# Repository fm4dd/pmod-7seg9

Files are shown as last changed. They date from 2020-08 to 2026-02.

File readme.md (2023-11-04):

## 7SEG9 PMOD



### Description

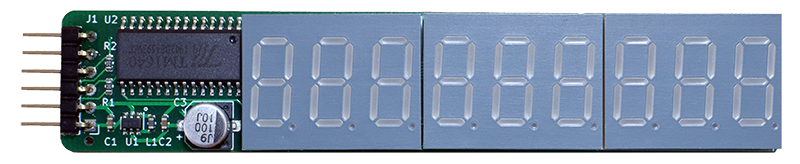
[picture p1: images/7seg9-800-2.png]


This PMOD provides a 9-digit (3x3) 7-segment LED display output to FPGA designs via a single row PMOD connector. The LED segments are driven by the TM1640 LED driver IC from Titan Microelectronics. The TM1640 can only handle "common cathode" display types. It implements the required multiplexing, LED resistance and 8-level output power control that greatly reduces the passive components needed to drive LED displays. The TM1640 driver IC interfaces with application logic through a simplified two-wire serial protocol that has similarities with I2C. A small DCDC boost converter SGM6603 raises the 3.3V PMOD voltage to the 5V operating voltage needed by the TM1640 driver IC.

http://fpga.fm4dd.com/

*Note:* The 7SEG9 PMOD draws 220-250mA current over 9 digits. During power on/off, the peak current can reach 500mA. This needs attention for boards with weak power supply.

### Schematic
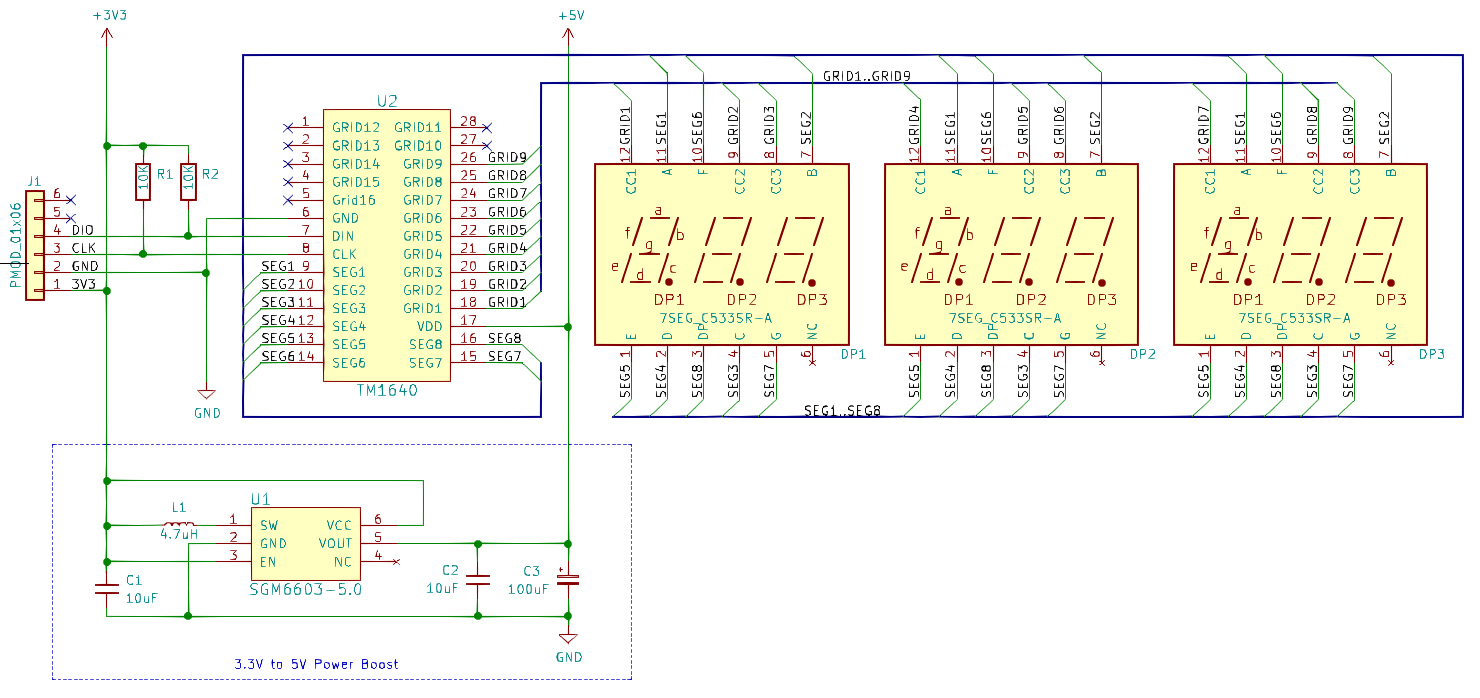
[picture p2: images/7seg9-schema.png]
7SEG9 PMOD Schematics


### PCB Gerber
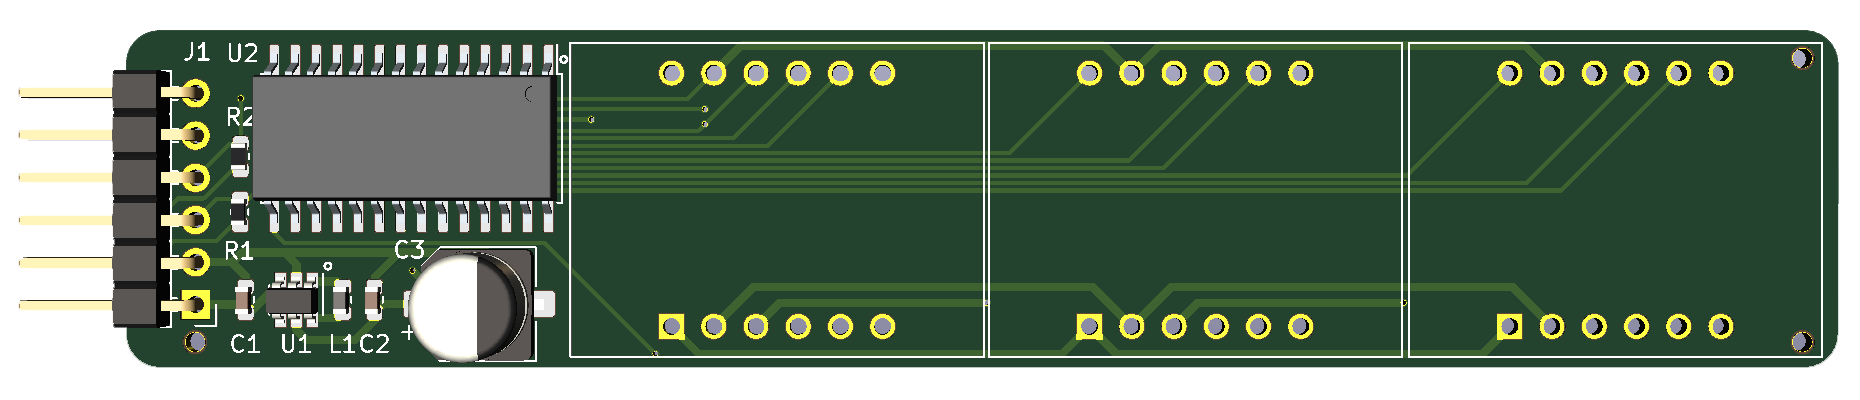
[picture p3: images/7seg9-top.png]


[7SEG4 PMOD Gerber V1.2](fabfiles/v12/20200520-7seg9-gerber-v12.zip)

### Pin Assignments

<table>
  <tr><th>PMOD Pinout</th><th>Pin</th><th>Label</th><th>Function</th></tr>
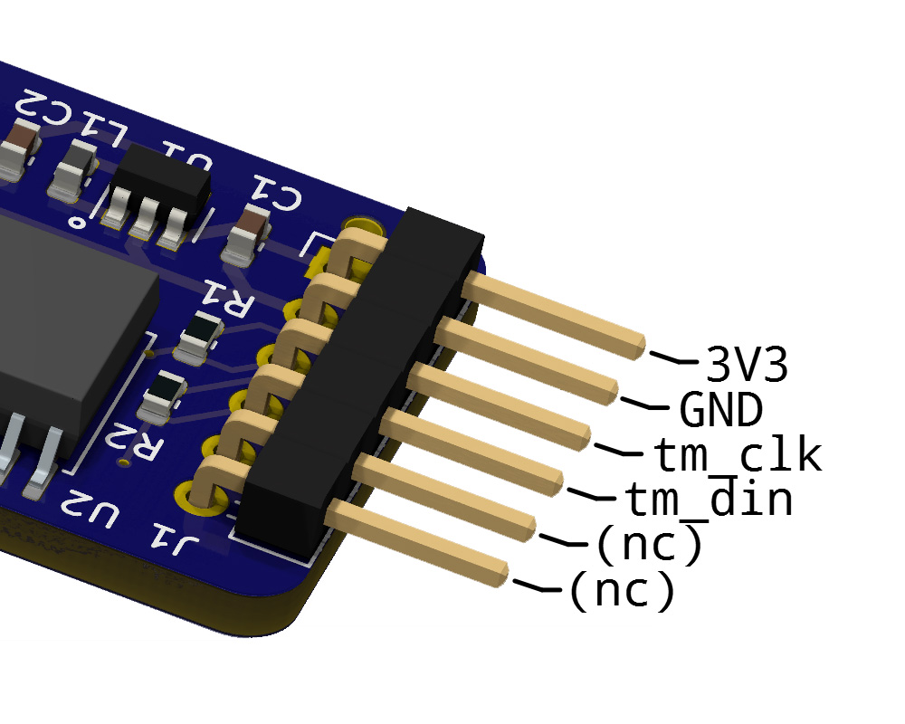
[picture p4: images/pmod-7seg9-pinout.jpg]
  <tr><td rowspan="6"></td>
    <td>1</td><td>n/c</td><td>(not connected)</td></tr>
    <tr><td>2</td><td>n/c</td><td>(not connected)</td></tr>
    <tr><td>3</td><td>tm_din</td><td>LED control data</td></tr>
    <tr><td>4</td><td>tm_clk</td><td>Bus Clock (<1MHz)</td></tr>
    <tr><td>5</td><td>GND</td><td>PMOD Power</td></tr>
    <tr><td>6</td><td>3V3</td><td>PMOD Power</td></tr>
</table>

### Example Code

The following platform code examples demonstrate the board function for quick verification.

| Platform | Test Program location | Description |
|---|---|---|
| Arduino IDE |[examples/arduino](examples/arduino) | Arduino IDE code (tested on PMOD2RPI Seeedstudio XIAO) |
| Raspberry Pi|[examples/pi-tm1640](examples/pi-tm1640) | Linux control program in 'C', using the libgpiod interface |
|IceBreaker|[examples/icebreaker](examples/icebreaker)| Verilog project for the IceBreaker FPGA (Lattice iCE40 FPGA family) |
| ULX3S |[examples/ulx3s](examples/ulx3s) | Verilog project for Radiona ULX3S FPGA (Lattice ECP5 FPGA family) |
| GateMate |[examples/gatemate](examples/gatemate) | Verilog project for the Cologne Chip Gatemate E1 FPGA board |

### PMOD-7Seg9 Function Tests

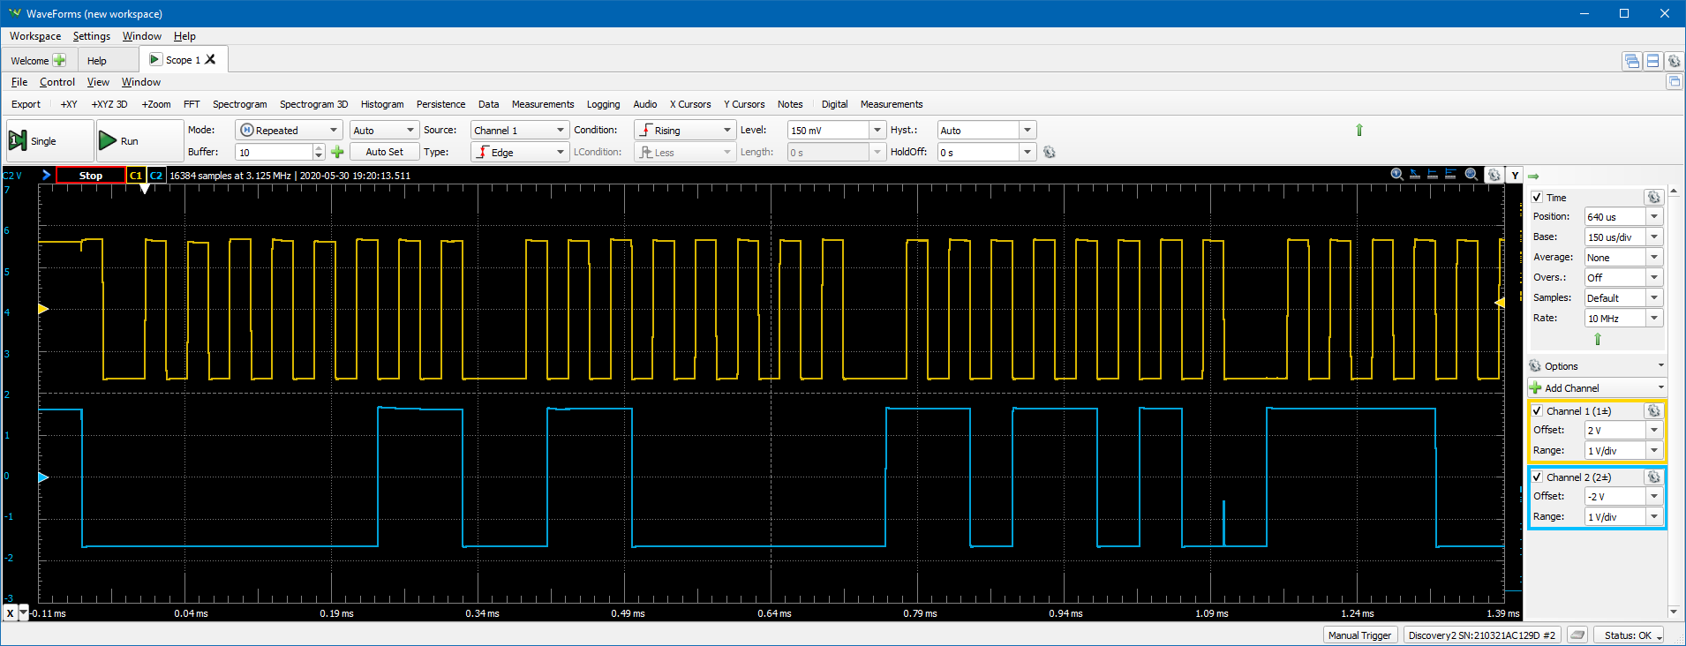
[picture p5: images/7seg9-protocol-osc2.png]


The oscilloscope visualizes the protocol data transmission. Blue = data signal, Orange = clock signal.

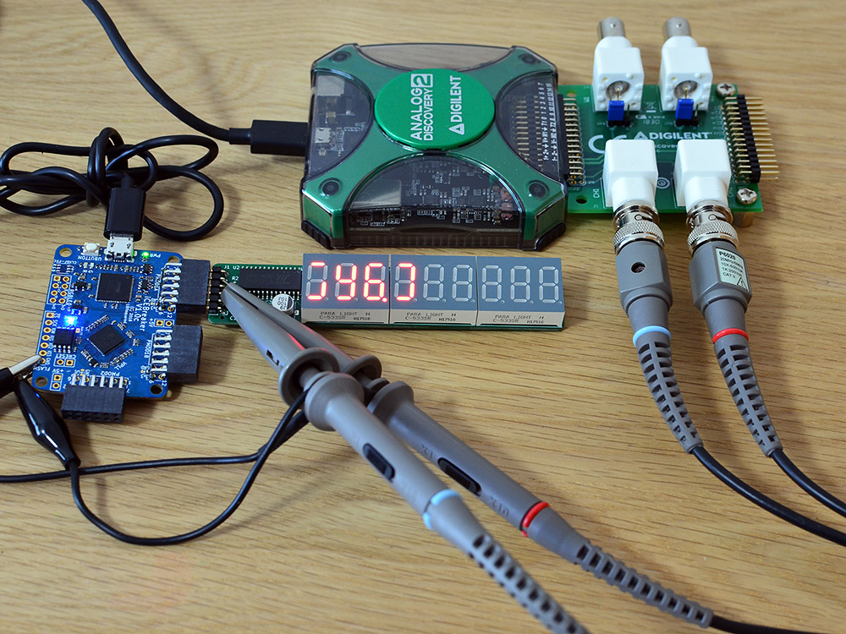
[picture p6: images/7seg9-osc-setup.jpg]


7SEG9 PMOD connected to a Icebreaker v1.0 board, during protocol analysis

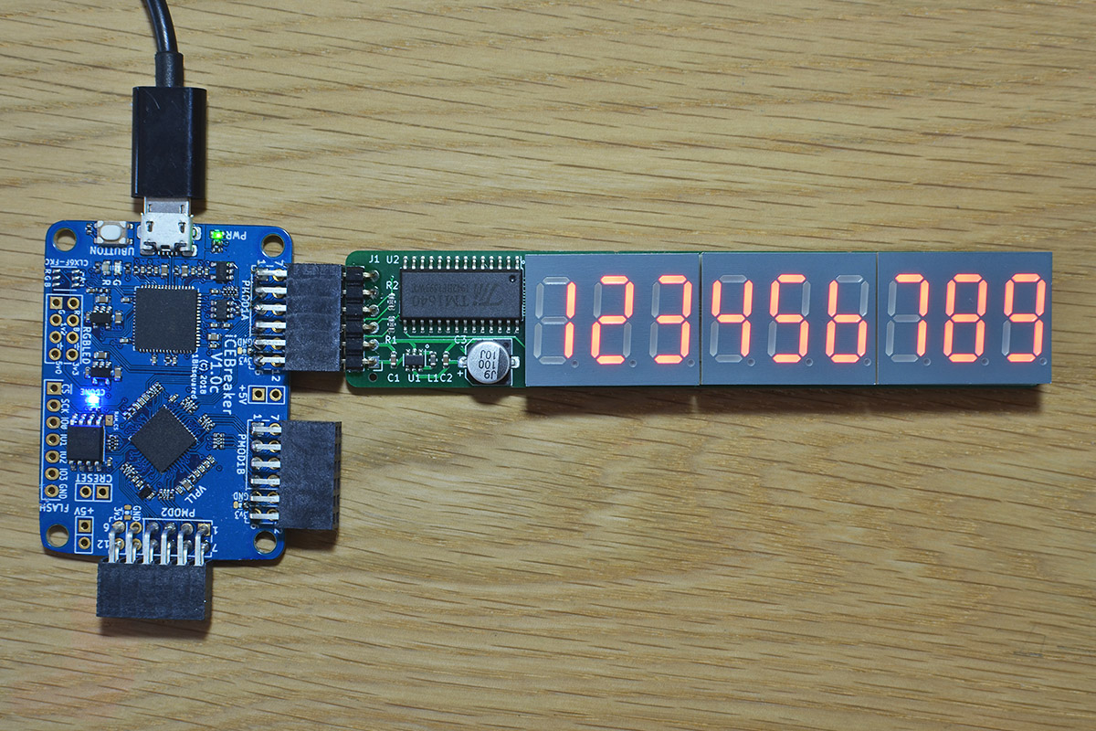
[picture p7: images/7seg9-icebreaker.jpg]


7SEG9 PMOD, connected to the Icebreaker FPGA board

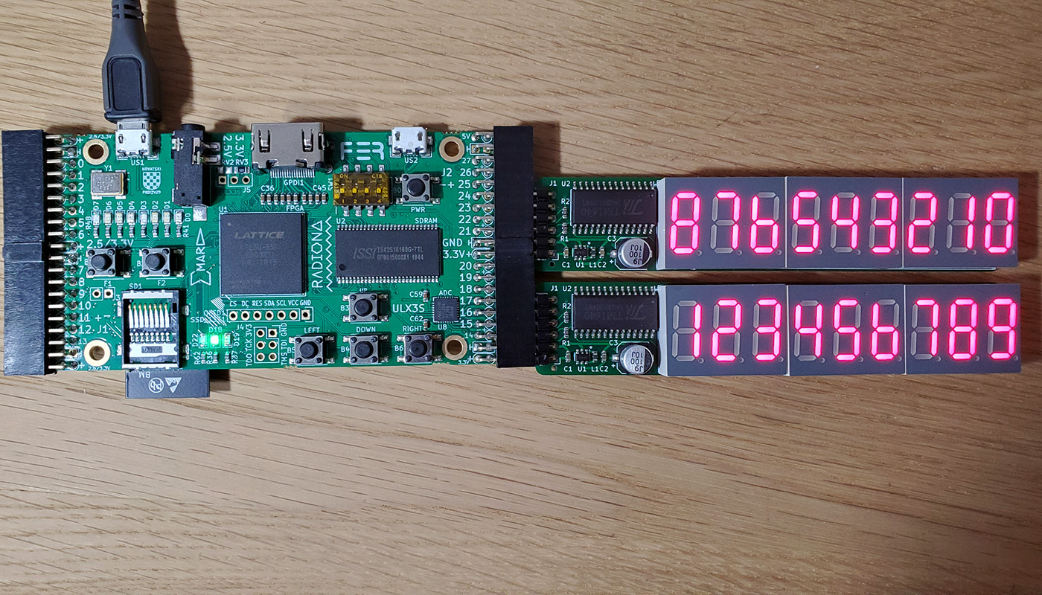
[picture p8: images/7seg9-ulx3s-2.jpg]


Two 7seg9 PMODs, connected to a ULX3S (Lattice ECP5 85K) board

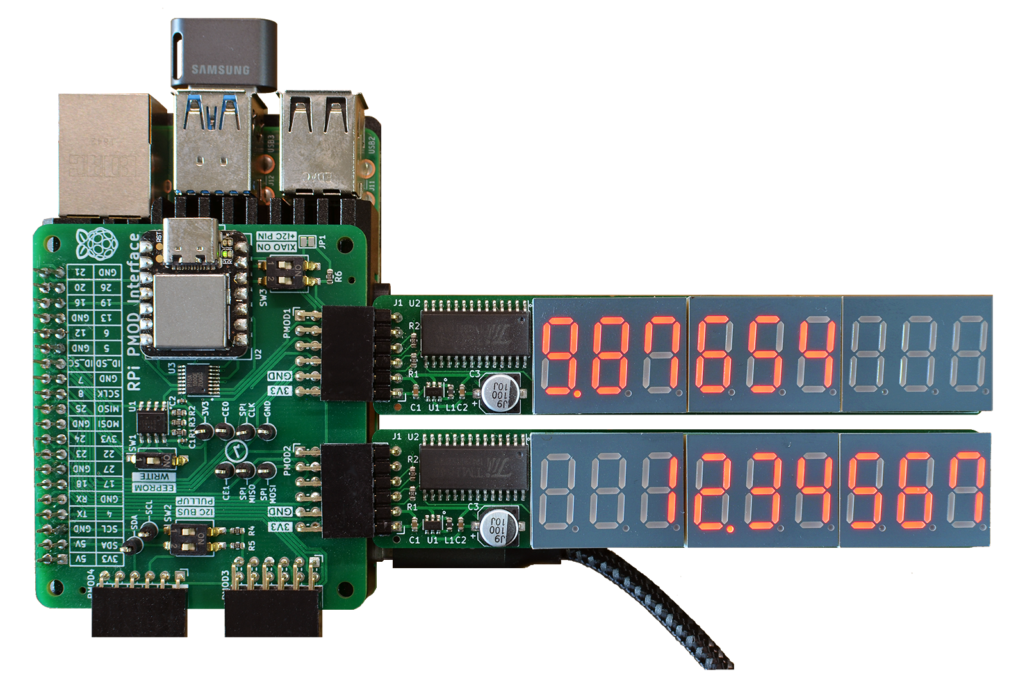
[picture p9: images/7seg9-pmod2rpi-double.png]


Two 7seg9 PMODs, connected to a Raspberry Pi via the PMOD2RPI interface board

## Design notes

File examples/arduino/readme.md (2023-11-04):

## Example code Pmod 7SEG9

The Arduino example program validates the function of the PMOD 7SEG9 module on the PMOD2RPI board, using the Seeedstudio XIAO MCU. It writes the numbers '123454321' to be displayed on the nine seven-segment digits. The PMOD 7SEG9 module is connected to PMOD1 lower pinrow.

The power draw for the PMOD tends to overload the XIAO MCU, and the PMOD2RPI board is best powered separately, e.g. through the Raspberry Pi header.

### Usage

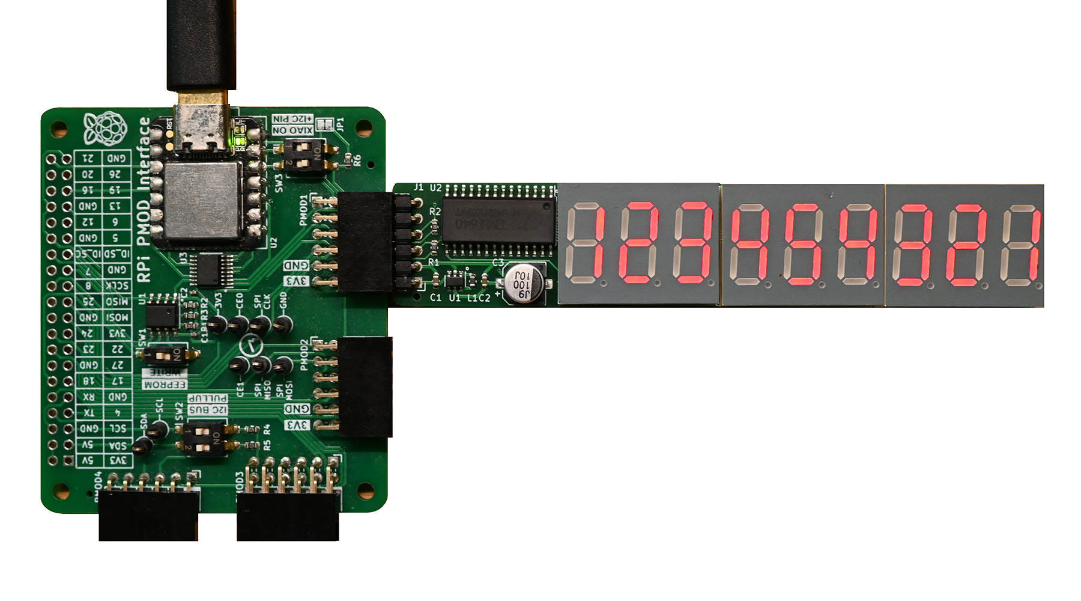
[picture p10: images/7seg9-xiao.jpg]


 The PMOD 7SEG9 module running the demo sketch on the PMOD2RPI board.

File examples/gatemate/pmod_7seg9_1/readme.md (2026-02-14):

## Example code Pmod 7SEG9

This Verilog example program validates the function of the PMOD 7SEG9 module on the Gatemate E1 board from Cologne Chip. It writes the numbers '123456789' to be displayed on the nine seven-segment digits. 

The constraints have the PMOD 7SEG9 module connected to PMODB lower pinrow.

### Usage

Synthesis
```
fm@nuc7fpga:~/fpga/hardware/pmod-7seg9/examples/gatemate/pmod_7seg9_1$ make
/home/fm/oss-cad-suite/bin/yosys -ql log/synth.log -p 'read -sv ./src/pmod_7seg9_1.v ./src/tm1640.v; synth_gatemate -top pmod_7seg9_1 -luttree -nomx8 -vlog net/pmod_7seg9_1_synth.v; write_json net/pmod_7seg9_1_synth.json'

=== pmod_7seg9_1 ===

        +----------Local Count, excluding submodules.
        |
      185 wires
      329 wire bits
       23 public wires
       74 public wire bits
        3 ports
        3 port bits
      247 cells
        1   $scopeinfo
       35   CC_ADDF
        1   CC_BUFG
       58   CC_DFF
        1   CC_IBUF
       65   CC_L2T4
       42   CC_L2T5
       25   CC_LUT2
       15   CC_MX2
        2   CC_MX4
        2   CC_OBUF
...
```

Place and route:
```
fm@nuc7fpga:~/fpga/hardware/pmod-7seg9/examples/gatemate/pmod_7seg9_1$ make impl
test -e src/gm-proto.ccf || exit
/home/fm/oss-cad-suite/bin/nextpnr-himbaechel --device=CCGM1A1 --json net/pmod_7seg9_1_synth.json --write net/pmod_7seg9_1_impl.v -o out=net/pmod_7seg9_1_impl.txt -o ccf=src/gm-proto.ccf --router router2 > log/impl.log
Info: Using uarch 'gatemate' for device 'CCGM1A1'
...
Info: Device utilisation:
Info: 	            USR_RSTN:       0/      1     0%
Info: 	            CPE_COMP:       0/  20480     0%
Info: 	         CPE_CPLINES:       4/  20480     0%
Info: 	               IOSEL:       3/    162     1%
Info: 	                GPIO:       3/    162     1%
Info: 	               CLKIN:       1/      1   100%
Info: 	              GLBOUT:       1/      1   100%
Info: 	                 PLL:       0/      4     0%
Info: 	            CFG_CTRL:       0/      1     0%
Info: 	              SERDES:       0/      1     0%
Info: 	              CPE_LT:     245/  40960     0%
Info: 	              CPE_FF:      58/  40960     0%
Info: 	           CPE_RAMIO:       2/  40960     0%
Info: 	            RAM_HALF:       0/     64     0%
...
Info: Program finished normally.
/home/fm/oss-cad-suite/bin/gmpack --input pmod_7seg9_1_impl.txt --bit pmod_7seg9_1.bit
```

Programming the FPGA:
```
fm@nuc7fpga:~/fpga/hardware/pmod-7seg9/examples/gatemate/pmod_7seg9_1$ make spi-flash 
/home/fm/oss-cad-suite/bin/openFPGALoader  -b gatemate_evb_spi -f --verify pmod_7seg9_1.bit
empty
write to flash
Jtag frequency : requested 6.00MHz    -> real 6.00MHz   
JEDEC ID: 0xc22817
Detected: Macronix MX25R6435F 128 sectors size: 64Mb
00000000 00000000 00000000 00
start addr: 00000000, end_addr: 00010000
Erasing: [==================================================] 100.00%
Done
Writing: [==================================================] 100.00%
Done
Verifying write (May take time)
Reading: [==================================================] 100.00%
Done
Wait for CFG_DONE DONE
```

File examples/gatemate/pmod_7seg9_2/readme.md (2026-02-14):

## Example code Pmod 7SEG9

This Verilog example program validates the function of the PMOD 7SEG9 module on the Gatemate E1 board from Cologne Chip.
It creates a timer '0-00-00-0' on the nine seven-segment digits. The onboard SW3 button acts as the 'start' and 'stop' command for the timer.

The constraints have the PMOD 7SEG9 module connected to PMODB lower pinrow.

### Usage

Synthesis
```
fm@nuc7fpga:~/fpga/hardware/pmod-7seg9/examples/gatemate/pmod_7seg9_1$ make
/home/fm/oss-cad-suite/bin/yosys -ql log/synth.log -p 'read -sv ./src/ctl_7seg9.v ./src/hexdigit.v ./src/pmod_7seg9_2.v ./src/tm1640.v; synth_gatemate -top pmod_7seg9_2 -luttree -nomx8; write_json net/pmod_7seg9_2_synth.json'

=== pmod_7seg9_2 ===

        +----------Local Count, excluding submodules.
        | 
      510 wires
     1323 wire bits
       97 public wires
      564 public wire bits
        5 ports
        5 port bits
      646 cells 
       12   $scopeinfo
      127   CC_ADDF
        1   CC_BUFG
      124   CC_DFF
        2   CC_IBUF
      171   CC_L2T4
      118   CC_L2T5
       15   CC_LUT1
       55   CC_LUT2
       16   CC_MX2
        2   CC_MX4
        3   CC_OBUF
...
```

Place and route:
```
fm@nuc7fpga:~/fpga/hardware/pmod-7seg9/examples/gatemate/pmod_7seg9_2$ make impl
test -e src/gm.ccf || exit
/home/fm/oss-cad-suite/bin/nextpnr-himbaechel --device=CCGM1A1 --json net/pmod_7seg9_2_synth.json -o out=pmod_7seg9_2_impl.txt -o ccf=src/gm.ccf --router router2 > log/impl.log
Info: Using uarch 'gatemate' for device 'CCGM1A1'
...
Info: Device utilisation:
Info: 	            USR_RSTN:       0/      1     0%
Info: 	            CPE_COMP:       0/  20480     0%
Info: 	         CPE_CPLINES:      14/  20480     0%
Info: 	               IOSEL:       5/    162     3%
Info: 	                GPIO:       5/    162     3%
Info: 	               CLKIN:       1/      1   100%
Info: 	              GLBOUT:       1/      1   100%
Info: 	                 PLL:       0/      4     0%
Info: 	            CFG_CTRL:       0/      1     0%
Info: 	              SERDES:       0/      1     0%
Info: 	              CPE_LT:     657/  40960     1%
Info: 	              CPE_FF:     124/  40960     0%
Info: 	           CPE_RAMIO:       3/  40960     0%
Info: 	            RAM_HALF:       0/     64     0%
...
Info: Program finished normally.
/home/fm/oss-cad-suite/bin/gmpack --input pmod_7seg9_2_impl.txt --bit pmod_7seg9_2.bit
```

Programming the FPGA:
```
fm@nuc7fpga:~/fpga/hardware/pmod-7seg9/examples/gatemate/pmod_7seg9_2$ make spi-flash
/home/fm/oss-cad-suite/bin/openFPGALoader  -b gatemate_evb_spi -f --verify pmod_7seg9_2.bit
empty
write to flash
Jtag frequency : requested 6.00MHz    -> real 6.00MHz   
JEDEC ID: 0xc22817
Detected: Macronix MX25R6435F 128 sectors size: 64Mb
00000000 00000000 00000000 00
start addr: 00000000, end_addr: 00010000
Erasing: [==================================================] 100.00%
Done
Writing: [==================================================] 100.00%
Done
Verifying write (May take time)
Reading: [==================================================] 100.00%
Done
Wait for CFG_DONE DONE
```

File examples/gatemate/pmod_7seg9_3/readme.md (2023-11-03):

## Example code Pmod 7SEG9

This Verilog example program validates the function of the PMOD 7SEG9 module on the Gatemate E1 board from Cologne Chip. It writes the numbers '123456789' to be displayed on the nine seven-segment digits. The default constraints have the PMOD 7SEG9 module connected to PMODB lower pinrow.

### Usage

Synthesis
```
fm@nuc7fpga:~/fpga/hardware/pmod-7seg9/examples/gatemate/pmod_7seg9_1$ make
/home/fm/cc-toolchain-linux/bin/yosys/yosys -ql log/synth.log -p 'read -sv ./src/pmod_7seg9_1.v ./src/tm1640.v; synth_gatemate -top pmod_7seg9_1 -nomx8 -vlog net/pmod_7seg9_1_synth.v'

=== pmod_7seg9_1 ===
 
   Number of wires:                140
   Number of wire bits:            395
   Number of public wires:          23
   Number of public wire bits:      68
   Number of memories:               0
   Number of memory bits:            0
   Number of processes:              0
   Number of cells:                212
     CC_ADDF                        28
     CC_BUFG                         1
     CC_DFF                         52
     CC_IBUF                         1
     CC_LUT1                         7
     CC_LUT2                        28
     CC_LUT3                        19
     CC_LUT4                        72
     CC_MX4                          2
     CC_OBUF                         2
...
```

Place and route:
```
fm@nuc7fpga:~/fpga/hardware/pmod-7seg9/examples/gatemate/pmod_7seg9_1$ make impl
test -e src/gm-proto.ccf || exit
/home/fm/cc-toolchain-linux/bin/p_r/p_r -i net/pmod_7seg9_1_synth.v -o pmod_7seg9_1 -ccf src/gm-proto.ccf > log/impl.log

Utilization Report

 CPEs                    172 /  20480  (  0.8 %)
 -----------------------------------------------
   CPE Registers          52 /  40960  (  0.1 %)
     Flip-flops           52
     Latches               0

 GPIOs                     3 /    144  (  2.1 %)
...
```

Programming the FPGA:
```
fm@nuc7fpga:~/fpga/hardware/pmod-7seg9/examples/gatemate/pmod_7seg9_1$ make spi-flash
/home/fm/cc-toolchain-linux/bin/openFPGALoader/openFPGALoader  -b gatemate_evb_spi -f --verify pmod_7seg9_1_00.cfg
write to flash
Jtag frequency : requested 6.00MHz   -> real 6.00MHz  
Detail: 
Jedec ID          : c2
memory type       : 28
memory capacity   : 17
EDID + CFD length : c2
EDID              : 1728
CFD               : 
00
Detail: 
Jedec ID          : c2
memory type       : 28
memory capacity   : 17
EDID + CFD length : c2
EDID              : 1728
CFD               : 
flash chip unknown: use basic protection detection
Erasing: [==================================================] 100.00%
Done
Writing: [==================================================] 100.00%
Done
Verifying write (May take time)
Read flash : [==================================================] 100.00%
Done
Wait for CFG_DONE DONE
```

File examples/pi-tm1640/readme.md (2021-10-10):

## Pi-TM1640

Linux 'C' Control Code for designs based on the Titan Micro LED Driver IC TM1640.
Implemented and tested on a Raspberry Pi, using the PMOD2RPI interface board and a PMOD-7SEG9 module. 

The code defaults the clock/data pins to GPIO 18/26 located on PMOD1 lower row.
Calling the control program with -c/-d arguments sets the pins to other values.
To operate the PMOD-7SEG9 module on PMOD2 lower row, use ./settm1640 -c 24 -d 23.

### Prerequisites

```
pi@pi-ms05:~ $ sudo apt install libgpiod-dev
```

### Compilation

```
pi@pi-ms05:~/pmod2rpi/pi-tm1640 $ make
gcc -O3 -Wall -g   -c -o tm1640.o tm1640.c
gcc -O3 -Wall -g   -c -o settm1640.o settm1640.c
gcc tm1640.o settm1640.o -o settm1640 -lgpiod
```

### Usage
```
pi@pi-ms05:~/pmod2rpi/pi-tm1640 $ ./settm1640
Usage: settm1640 [-c <clockpin>] [-d <datapin>] -b <brightness>
       settm1640 [-c <clockpin>] [-d <datapin>] [-i] -o <display-digits> [-a <l|r>]
       settm1640 [-c <clockpin>] [-d <datapin>] -e
       settm1640 [-c <clockpin>] [-d <datapin>] -o

Command line parameters have the following format:
   -a   left/right alignment either 'l' or 'r' (default)
   -b   enable display with LED brightness 0..7
        example: -b 5
   -c   clock pin GPIO number
   -d   data pin GPIO number
   -e   empty (clear) the display
   -i   vertical inverted (together with -w)
   -o   display off switch
   -w   1..9-digit output string to display
        example: -o 12345678
   -h   display this message
   -v   enable debug output

Usage examples:
./settm1640 -c 18 -d 26 -b 2
./settm1640 -c 18 -d 26 -e
./settm1640 -c 18 -d 26 -o
./settm1640 -c 18 -d 26 -w 876543210
```

### Examples

Enable the 7-Seg display connected to PMOD2RPI PMOD1 (lower row), with verbose on:
```
pi@pi-ms05:~/pmod2rpi/pi-tm1640 $ ./settm1640 -v -b 4
Debug: arg -b, value 4
Debug: ts=[1633842468] date=Sun Oct 10 14:07:48 2021
Debug: tm1640_init(c=18, d=26)
Debug: tm1640_sendCmd(0x8C)
  Debug: tm1640_sendRaw(0x8C) 10001100 ...complete
...Cmd done
Debug: tm1640_on(4) complete
```

Write the string "9.87654" to the 7-Seg display on PMOD2RPI PMOD1 (lower row), with verbose on:
```
pi@pi-ms05:~/pmod2rpi/pi-tm1640 $ ./settm1640 -v -w 9.87654
Debug: arg -w, value 9.87654
Debug: ts=[1633842358] date=Sun Oct 10 14:05:58 2021
Debug: tm1640_init(c=18, d=26)
Debug: tm1640_write(s=9.87654 l=7 i=0):
  Debug: char 9 = 01101111
  Debug: char . = 10000000
  Debug: char 8 = 01111111
  Debug: char 7 = 00100111
  Debug: char 6 = 01111101
  Debug: char 5 = 01101101
  Debug: char 4 = 01100110
Debug: tm1640_sendCmd(0x44)
  Debug: tm1640_sendRaw(0x44) 01000100 ...complete
...Cmd done
  Debug: tm1640_sendRaw(0xC0) 11000000 ...complete
  Debug: tm1640_sendRaw(0xEF) 11101111 ...complete
  Debug: tm1640_sendRaw(0x7F) 01111111 ...complete
  Debug: tm1640_sendRaw(0x27) 00100111 ...complete
  Debug: tm1640_sendRaw(0x7D) 01111101 ...complete
  Debug: tm1640_sendRaw(0x6D) 01101101 ...complete
  Debug: tm1640_sendRaw(0x66) 01100110 ...complete
  Debug: tm1640_sendRaw(0x00) 00000000 ...complete
  Debug: tm1640_sendRaw(0x00) 00000000 ...complete
  Debug: tm1640_sendRaw(0x00) 00000000 ...complete
...write done
```

Write the same string "9.87654" with verbose on, but with the output vertically inverted:
```
pi@pi-ms05:~/pmod2rpi/pi-tm1640 $ ./settm1640 -v -w 9.87654 -i
Debug: arg -w, value 9.87654
Debug: arg -i
Debug: ts=[1633842391] date=Sun Oct 10 14:06:31 2021
Debug: tm1640_init(c=18, d=26)
Debug: tm1640_write(s=9.87654 l=7 i=1):
  Debug: invert 01100110 = 01110100
  Debug: char 4 = 01110100
  Debug: invert 01101101 = 01101101
  Debug: char 5 = 01101101
  Debug: invert 01111101 = 01101111
  Debug: char 6 = 01101111
  Debug: invert 00100111 = 00111100
  Debug: char 7 = 00111100
  Debug: invert 01111111 = 01111111
  Debug: char 8 = 01111111
  Debug: invert 10000000 = 10000000
  Debug: char . = 10000000
  Debug: invert 01101111 = 01111101
  Debug: char 9 = 01111101
Debug: tm1640_sendCmd(0x44)
  Debug: tm1640_sendRaw(0x44) 01000100 ...complete
...Cmd done
  Debug: tm1640_sendRaw(0xC0) 11000000 ...complete
  Debug: tm1640_sendRaw(0x74) 01110100 ...complete
  Debug: tm1640_sendRaw(0x6D) 01101101 ...complete
  Debug: tm1640_sendRaw(0x6F) 01101111 ...complete
  Debug: tm1640_sendRaw(0x3C) 00111100 ...complete
  Debug: tm1640_sendRaw(0xFF) 11111111 ...complete
  Debug: tm1640_sendRaw(0x7D) 01111101 ...complete
  Debug: tm1640_sendRaw(0x00) 00000000 ...complete
  Debug: tm1640_sendRaw(0x00) 00000000 ...complete
  Debug: tm1640_sendRaw(0x00) 00000000 ...complete
...write done
```

Using the -e argument clears the display (writing 'null' bytes):
``` 
pi@pi-ms05:~/pmod2rpi/pi-tm1640 $ ./settm1640 -v -e
Debug: arg -e
Debug: ts=[1633842773] date=Sun Oct 10 14:12:53 2021
Debug: tm1640_init(c=18, d=26)
  Debug: tm1640_sendRaw(0xC0) 11000000 ...complete
  Debug: tm1640_sendRaw(0x00) 00000000 ...complete
  Debug: tm1640_sendRaw(0x00) 00000000 ...complete
  Debug: tm1640_sendRaw(0x00) 00000000 ...complete
  Debug: tm1640_sendRaw(0x00) 00000000 ...complete
  Debug: tm1640_sendRaw(0x00) 00000000 ...complete
  Debug: tm1640_sendRaw(0x00) 00000000 ...complete
  Debug: tm1640_sendRaw(0x00) 00000000 ...complete
  Debug: tm1640_sendRaw(0x00) 00000000 ...complete
  Debug: tm1640_sendRaw(0x00) 00000000 ...complete
  Debug: tm1640_sendRaw(0x00) 00000000 ...complete
  Debug: tm1640_sendRaw(0x00) 00000000 ...complete
  Debug: tm1640_sendRaw(0x00) 00000000 ...complete
  Debug: tm1640_sendRaw(0x00) 00000000 ...complete
  Debug: tm1640_sendRaw(0x00) 00000000 ...complete
  Debug: tm1640_sendRaw(0x00) 00000000 ...complete
  Debug: tm1640_sendRaw(0x00) 00000000 ...complete
```

We can turn the display off with -o. This keeps the previous content, and a turn-on restores the output:
```
pi@pi-ms05:~/pmod2rpi/pi-tm1640 $ ./settm1640 -v -o
Debug: arg -o
Debug: ts=[1633842994] date=Sun Oct 10 14:16:34 2021
Debug: tm1640_init(c=18, d=26)
Debug: tm1640_sendCmd(0x80)
  Debug: tm1640_sendRaw(0x80) 10000000 ...complete
...Cmd done
Debug: tm1640_off() complete

pi@pi-ms05:~/pmod2rpi/pi-tm1640 $ ./settm1640 -v -b 4
Debug: arg -b, value 4
Debug: ts=[1633842997] date=Sun Oct 10 14:16:37 2021
Debug: tm1640_init(c=18, d=26)
Debug: tm1640_sendCmd(0x8C)
  Debug: tm1640_sendRaw(0x8C) 10001100 ...complete
...Cmd done
Debug: tm1640_on(4) complete
```

Multiple 7-Segment PMODs can be controlled in parallel by specifying the clock/data pins:
```
pi@pi-ms05:~/pmod2rpi/pi-tm1640 $ ./settm1640 -v -c 24 -d 23 -w "  12.34567"
Debug: arg -c, value 24
Debug: arg -d, value 23
Debug: arg -w, value   12.34567
Debug: ts=[1633843283] date=Sun Oct 10 14:21:23 2021
Debug: tm1640_init(c=24, d=23)
Debug: tm1640_write(s=  12.34567 l=10 i=0):
  Debug: char   = 00000000
  Debug: char   = 00000000
  Debug: char 1 = 00000110
  Debug: char 2 = 01011011
  Debug: char . = 10000000
  Debug: char 3 = 01001111
  Debug: char 4 = 01100110
  Debug: char 5 = 01101101
  Debug: char 6 = 01111101
  Debug: char 7 = 00100111
Debug: tm1640_sendCmd(0x44)
  Debug: tm1640_sendRaw(0x44) 01000100 ...complete
...Cmd done
  Debug: tm1640_sendRaw(0xC0) 11000000 ...complete
  Debug: tm1640_sendRaw(0x00) 00000000 ...complete
  Debug: tm1640_sendRaw(0x00) 00000000 ...complete
  Debug: tm1640_sendRaw(0x06) 00000110 ...complete
  Debug: tm1640_sendRaw(0xDB) 11011011 ...complete
  Debug: tm1640_sendRaw(0x4F) 01001111 ...complete
  Debug: tm1640_sendRaw(0x66) 01100110 ...complete
  Debug: tm1640_sendRaw(0x6D) 01101101 ...complete
  Debug: tm1640_sendRaw(0x7D) 01111101 ...complete
  Debug: tm1640_sendRaw(0x27) 00100111 ...complete
...write done
```

This example with 7seg9 PMODs connected to a Raspberry Pi via the PMOD2RPI interface board:


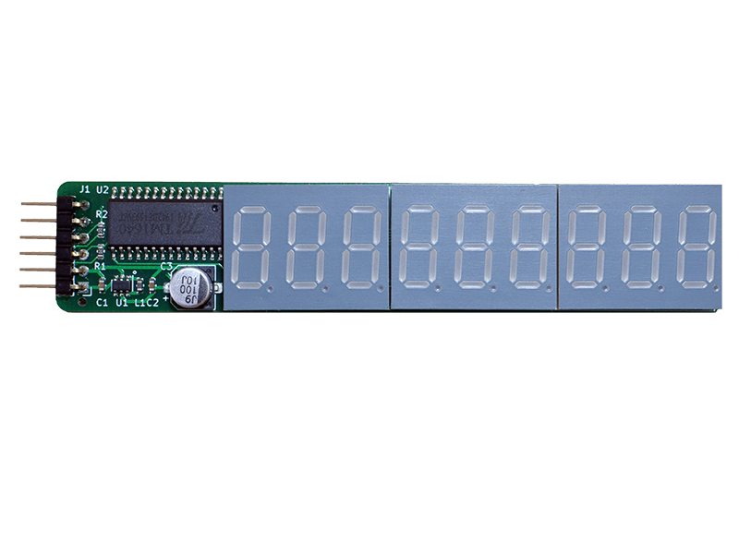
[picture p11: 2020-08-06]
images/7seg9-800.png

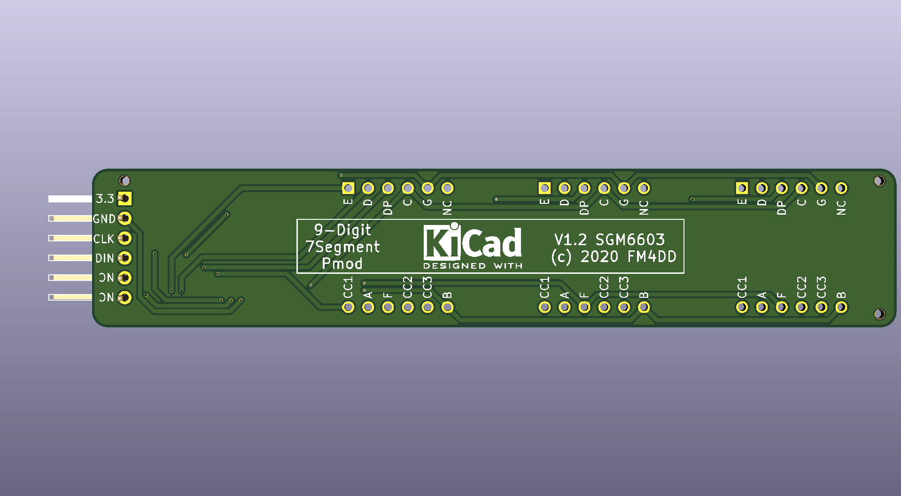
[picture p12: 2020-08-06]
images/7seg9-back.png

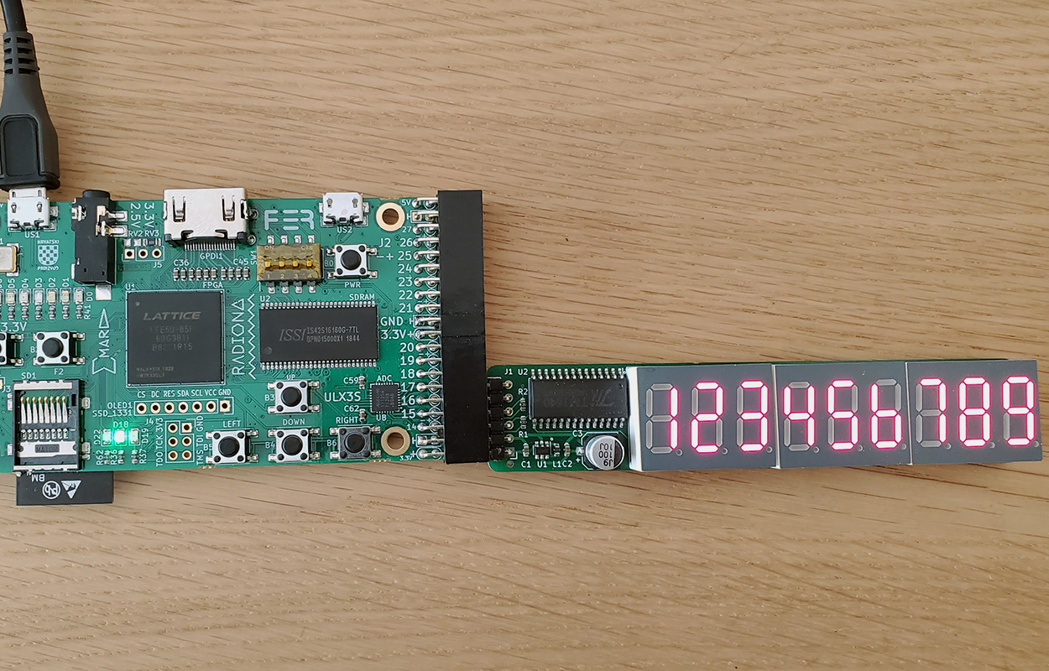
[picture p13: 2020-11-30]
images/7seg9-ulx3s.jpg

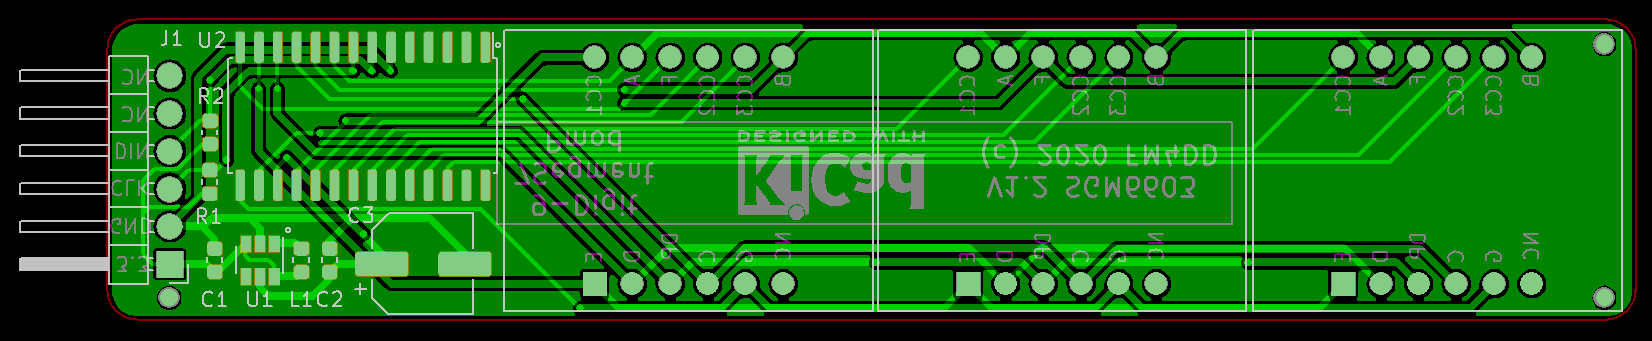
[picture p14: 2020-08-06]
images/7seg9-gerber.png

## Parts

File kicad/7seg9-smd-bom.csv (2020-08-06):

Comment | Designator | Footprint | LCSC
10uF | C1, C2 | Capacitor_SMD:C_0603_1608Metric
100uF | C3 | Capacitor_SMD:CP_Elec_6.3x5.4
7SEG_C533SR-A | DP1, DP2, DP3 | 01_FM4DD:7SEG_CS533SR-A
PMOD_01x06 | J1 | Connector_PinHeader_2.54mm:PinHeader_1x06_P2.54mm_Horizontal
4.7uH | L1 | Inductor_SMD:L_0603_1608Metric
10K | R1, R2 | Resistor_SMD:R_0603_1608Metric
SGM6603-5.0 | U1 | Package_TO_SOT_SMD:SOT-23-6
TM1640 | U2 | 01_FM4DD:SOP-28_7.5x17.9mm_P1.27mm

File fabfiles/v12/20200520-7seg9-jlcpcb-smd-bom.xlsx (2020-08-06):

Comment | Designator | Footprint | LCSC Part #（optional）
10uF | C1 | C_0603
10uF | C2 | C_0603
100uF | C3 | ECAP_6.3x5.4
4.7uH | L1 | L_0603
10K | R1, R2 | R_0603
SGM6603 | U1 | SOT-23-6
TM1640 | U2 | SOP-28_7.5x17.9mm_P1.27mm

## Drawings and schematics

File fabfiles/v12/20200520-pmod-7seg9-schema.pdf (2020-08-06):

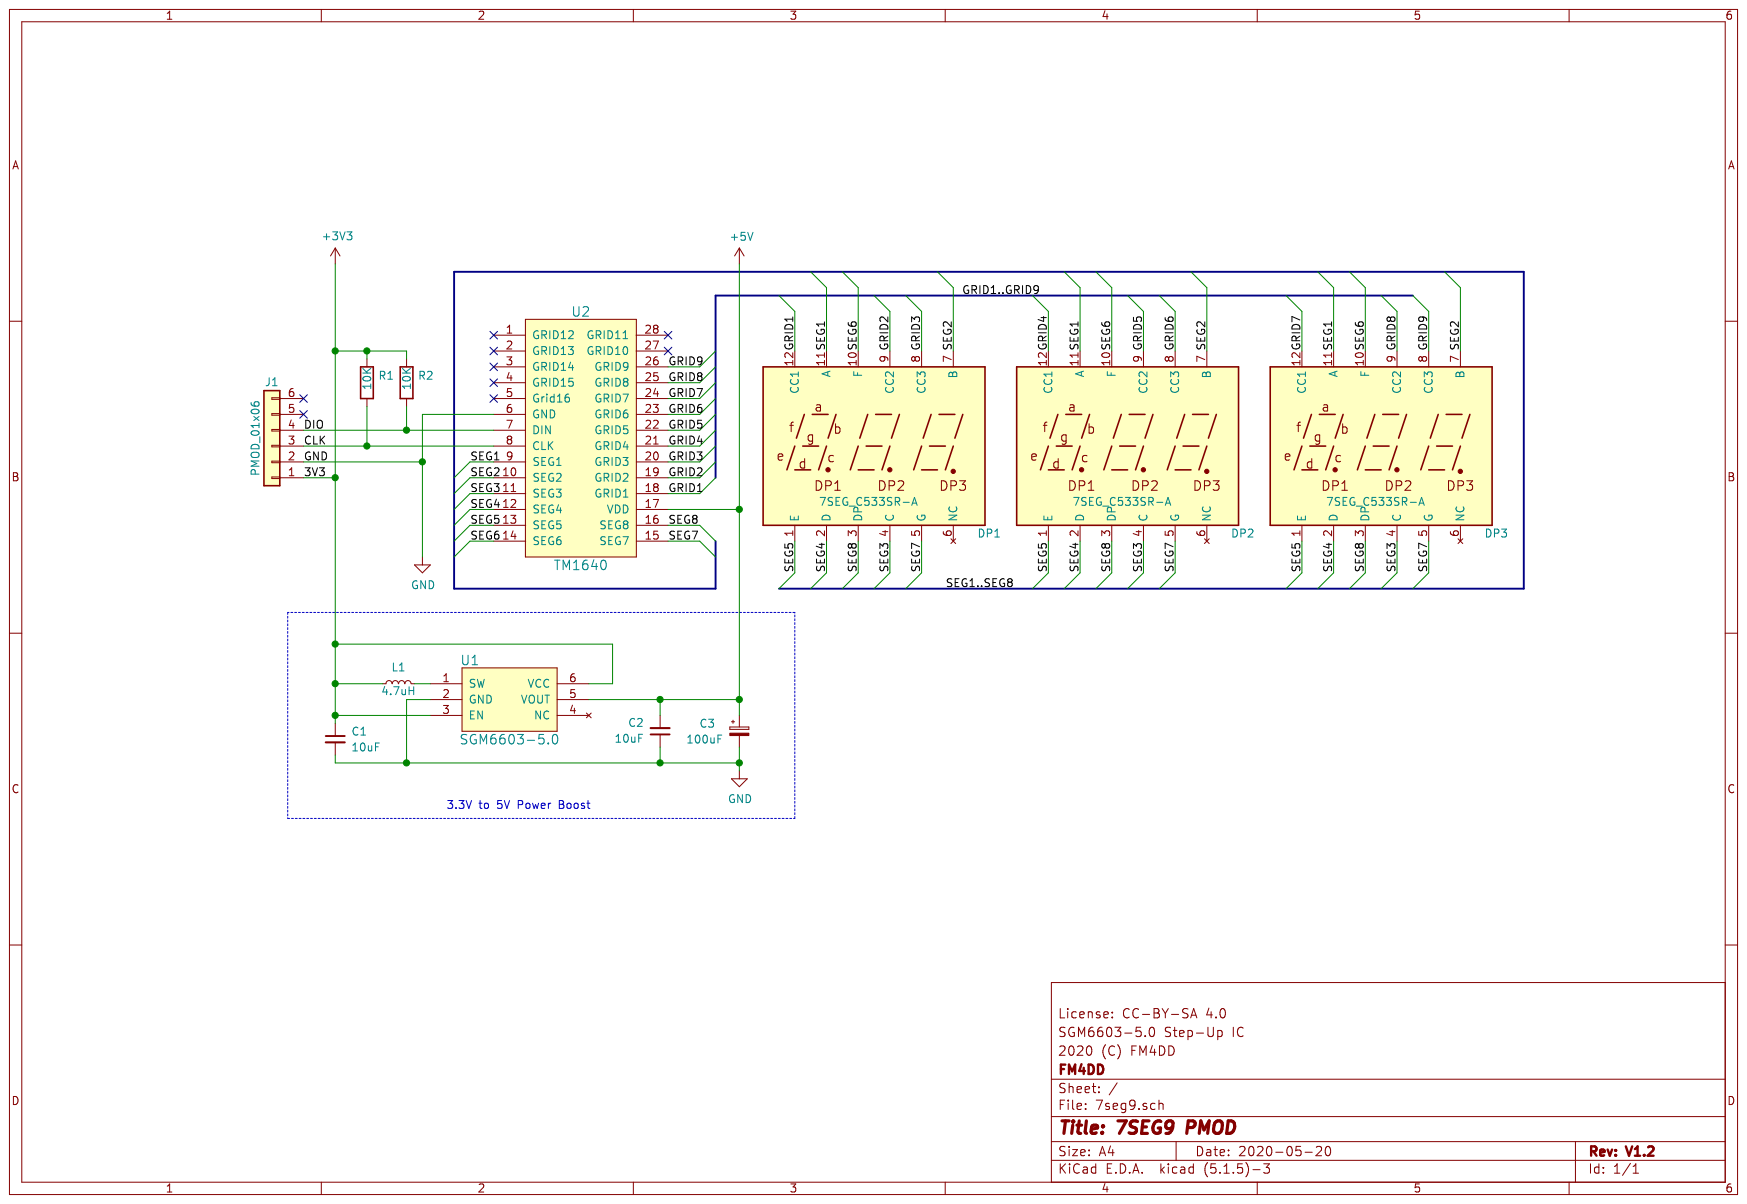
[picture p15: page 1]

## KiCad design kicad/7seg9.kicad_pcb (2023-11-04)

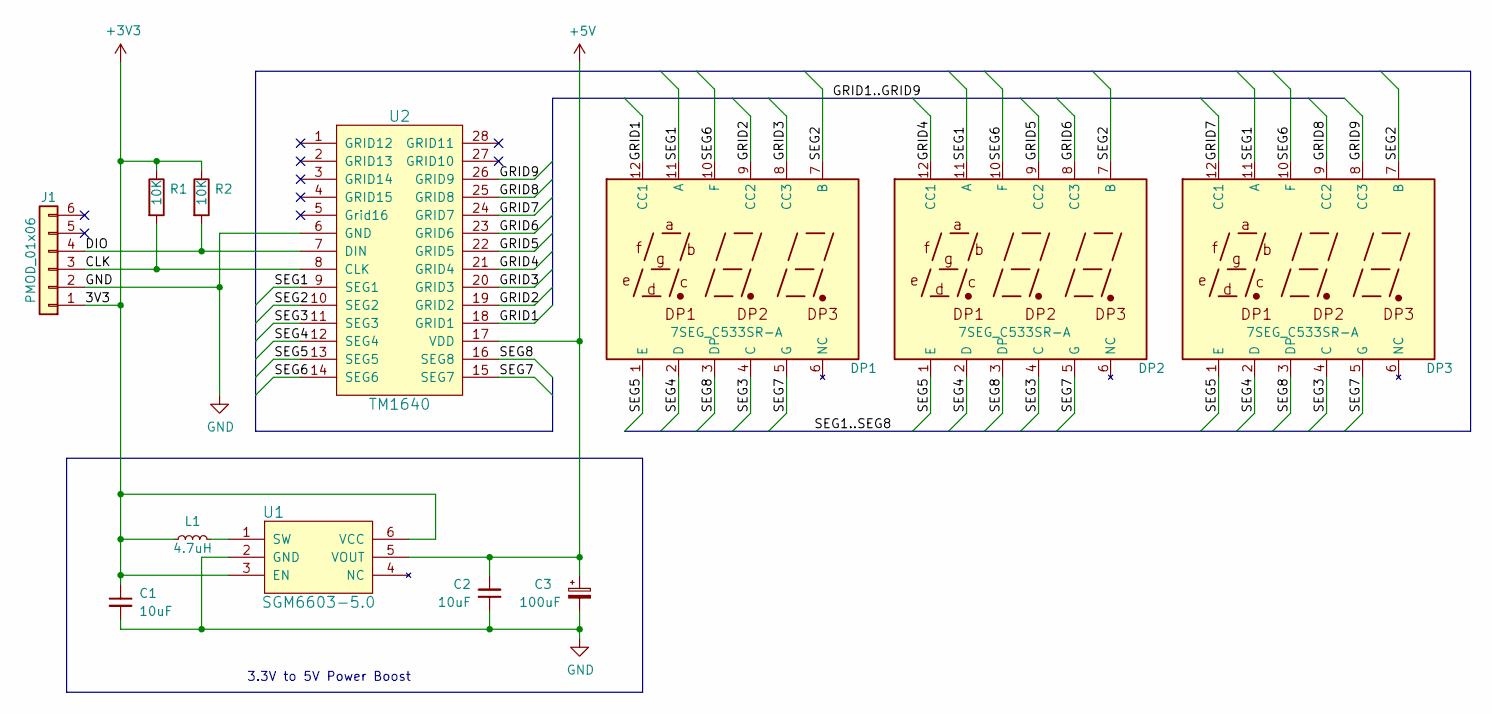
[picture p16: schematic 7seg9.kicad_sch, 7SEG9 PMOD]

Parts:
C1, C2: 10uF; C_0603_1608Metric
C3: 100uF; CP_Elec_6.3x5.4
DP1, DP2, DP3: 7SEG_C533SR-A; 7SEG_CS533SR-A
J1: PMOD_01x06; PinHeader_1x06_P2.54mm_Horizontal
L1: 4.7uH; L_0603_1608Metric
R1, R2: 10K; R_0603_1608Metric
U1: SGM6603-5.0; SOT-23-6
U2: TM1640; SOP-28_7.5x17.9mm_P1.27mm

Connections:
+3V3: C1.1, J1.1, L1.1, R1.1, R2.1, U1.3 (EN), U1.6 (VCC)
+5V: C2.2, C3.1, U1.5 (VOUT), U2.17 (VDD)
/CLK: J1.3, R1.2, U2.8 (CLK)
/DIO: J1.4, R2.2, U2.7 (DIN)
/GRID1: DP1.12 (CC1), U2.18 (GRID1)
/GRID2: DP1.9 (CC2), U2.19 (GRID2)
/GRID3: DP1.8 (CC3), U2.20 (GRID3)
/GRID4: DP2.12 (CC1), U2.21 (GRID4)
/GRID5: DP2.9 (CC2), U2.22 (GRID5)
/GRID6: DP2.8 (CC3), U2.23 (GRID6)
/GRID7: DP3.12 (CC1), U2.24 (GRID7)
/GRID8: DP3.9 (CC2), U2.25 (GRID8)
/GRID9: DP3.8 (CC3), U2.26 (GRID9)
/SEG1: DP1.11 (A), DP2.11 (A), DP3.11 (A), U2.9 (SEG1)
/SEG2: DP1.7 (B), DP2.7 (B), DP3.7 (B), U2.10 (SEG2)
/SEG3: DP1.4 (C), DP2.4 (C), DP3.4 (C), U2.11 (SEG3)
/SEG4: DP1.2 (D), DP2.2 (D), DP3.2 (D), U2.12 (SEG4)
/SEG5: DP1.1 (E), DP2.1 (E), DP3.1 (E), U2.13 (SEG5)
/SEG6: DP1.10 (F), DP2.10 (F), DP3.10 (F), U2.14 (SEG6)
/SEG7: DP1.5 (G), DP2.5 (G), DP3.5 (G), U2.15 (SEG7)
/SEG8: DP1.3 (DP), DP2.3 (DP), DP3.3 (DP), U2.16 (SEG8)
GND: C1.2, C2.1, C3.2, J1.2, U1.2 (GND), U2.6 (GND)
unnamed: L1.2, U1.1 (SW)

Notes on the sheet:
3.3V to 5V Power Boost

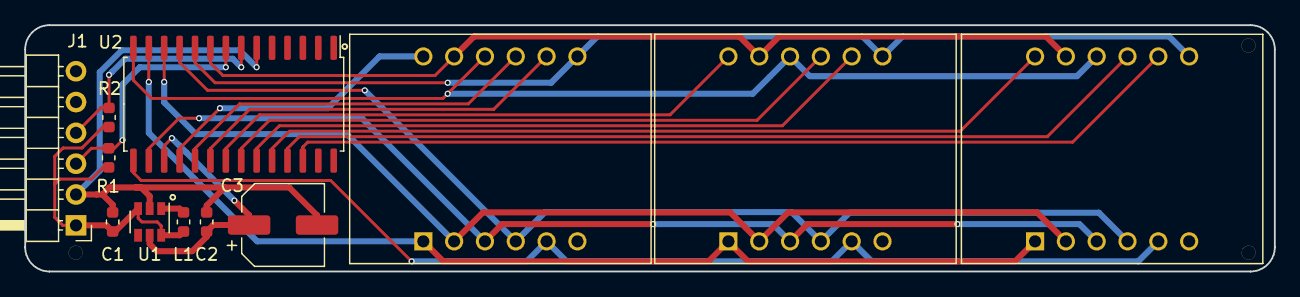
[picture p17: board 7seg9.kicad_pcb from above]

Board: 2 copper layers, 103.0 x 20.3 mm, 15 parts (0 on the bottom side), 23 nets.

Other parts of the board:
TOOLING_HOLE_1.152: TOOL2; SMD_TOOLING_HOLE_1.152mm
TOOLING_HOLE_1.152#2: TOOL3; SMD_TOOLING_HOLE_1.152mm
TOOLING_HOLE_1.152#3: TOOL1; SMD_TOOLING_HOLE_1.152mm

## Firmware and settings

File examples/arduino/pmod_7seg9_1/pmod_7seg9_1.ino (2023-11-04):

// pmod_7seg9_1.ino
//
// This program tests the pmod-7seg9 module
// connected to PMOD2RPI PMOD1 port, lower
// pin row. The code is based on the TM1638
// library code by Ricardo Batista, located
// https://github.com/rjbatista/tm1638-library/
//
// PMOD1 XIAO pin assignment:
// -----------------------------------------
// pmod1-5 = XIAO gpio D3  NC
// pmod1-6 = XIAO gpio D2  NC
// pmod1-7 = XIAO gpio D5  tm_din
// pmod1-8 = XIAO gpio D4  tm_clk
// -----------------------------------------
// Note:
// 1 PMOD2RPI switch SW3-1 in "ON" position
// The pmod power draw can be too high for
// some MCU, including the Seeedstudio XAIO 
// -----------------------------------------
#include "TM1640.h"

// params: dataPin, clockPin, activateDisplay (true/false), intensity (0..7)
TM1640 module(5, 4, true, 2);
// we can instantiate the module with activate and intensity default values,
// using only data and clock Pin, later use module.setupDisplay() to control.
//TM1640 module(5, 4);

void setup() {
  module.clearDisplay();
  // module.setupDisplay(true, 1);
  module.setDisplayToString("123454321");
}

void loop(){}

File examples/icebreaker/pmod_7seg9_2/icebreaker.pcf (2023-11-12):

# 12 MHz clock
set_io -nowarn clk        35

# RS232
set_io -nowarn RX          6
set_io -nowarn TX          9

# LEDs and Button
set_io -nowarn rst        10
set_io -nowarn LEDR_N     11
set_io -nowarn LEDG_N     37

# RGB LED Driver
set_io -nowarn LED_RED_N  39
set_io -nowarn LED_GRN_N  40
set_io -nowarn LED_BLU_N  41

# SPI Flash
set_io -nowarn FLASH_SCK  15
set_io -nowarn FLASH_SSB  16
set_io -nowarn FLASH_IO0  14
set_io -nowarn FLASH_IO1  17
set_io -nowarn FLASH_IO2  12
set_io -nowarn FLASH_IO3  13

# PMOD 1A
#set_io -nowarn P1A1        4
#set_io -nowarn P1A2        2
#set_io -nowarn P1A3       47
#set_io -nowarn P1A4       45
#set_io -nowarn P1A7        3
#set_io -nowarn P1A8       48
#set_io -nowarn P1A9       46
#set_io -nowarn P1A10      44

# PMOD 1B
#set_io -nowarn P1B1       43
#set_io -nowarn P1B2       38
#set_io -nowarn P1B3       34
#set_io -nowarn P1B4       31
#set_io -nowarn P1B7       42
#set_io -nowarn P1B8       36
#set_io -nowarn P1B9       32
#set_io -nowarn P1B10      28

# PMOD 2
#set_io -nowarn P2_1       27
#set_io -nowarn P2_2       25
#set_io -nowarn P2_3       21
#set_io -nowarn P2_4       19
#set_io -nowarn P2_7       26
#set_io -nowarn P2_8       23
#set_io -nowarn P2_9       20
#set_io -nowarn P2_10      18

set_io -nowarn tm_din     20
set_io -nowarn tm_clk     18

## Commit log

2020-08-06 initial upload
    [20200520-7seg9-jlcpcb-smd-bom.xlsx, 7seg9-smd-bom.csv, 7seg9.kicad_pcb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]
2021-10-10 add Linux driver example
2023-11-03 Kicad and OSS toolchain version upgrades
    [7seg9.kicad_pcb, 7seg9.kicad_sch, 7seg9.sch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]
2023-11-04 documentation update
    [20200520-7seg9-jlcpcb-smd-bom.xlsx, 7seg9.kicad_pcb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]
2023-11-04 Arduino example

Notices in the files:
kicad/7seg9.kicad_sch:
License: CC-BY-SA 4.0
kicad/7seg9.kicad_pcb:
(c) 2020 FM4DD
